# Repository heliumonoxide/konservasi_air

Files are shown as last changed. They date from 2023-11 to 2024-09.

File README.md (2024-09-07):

# Water Quality Monitoring Device
Banner Github Water Quality Monitoring
## Introduction
This project is **a Water Quality Monitoring System** supported by both a web interface and an OLED display. The device utilizes the SPIFFS (SPI Flash File System) feature of the ESP32 microcontroller to deploy a native web application (HTML, CSS, JavaScript) over a wide-area local network. The system directly links the web interface to real-time data received by the ESP32, providing users with seamless access to water quality metrics. 
 
### Concerns
The Drinking Fountain is essential for students at the Faculty of Engineering, Universitas Indonesia, providing water and reducing plastic use. However, concerns about water quality have led 60% of students to still purchase bottled water. A survey revealed that 90% of respondents believe the water quality in certain buildings is poor, particularly due to its taste. Addressing these concerns is crucial to encouraging students to trust and use the water fountains.

### Usage
1. The device measures all test parameters on drinking water samples.
2. It displays results in a human-readable format via an OLED screen.
3. The device sends water test data to a designed webpage.
4. Its microcontroller deploys a server-based webpage accessible to anyone on the UI Wi-Fi, providing water fountain quality information.

## PCB Design
PCB made using Altium and printed using PCB printing machine.
\


> Here are the made PCB picture
> \
> 
## Hardware Design
HardwareDesign-ezgif com-video-to-gif-converter

## Requirements Software
For installation, within Arduino IDE, the following libraries needs to be installed under Sketch -> Include Library -> Manage Libraries:
* ArduinoJson by Benoit Blanchon
* WebSockets by Markus Sattler
* WiFi 

The following to libraries need to be downloaded, unpacked and copied to the "Arduino" folder (Required for ESPAsyncWebServer)
- https://github.com/me-no-dev/ESPAsyncWebServerWater
- https://github.com/me-no-dev/AsyncTCP

Required to make SPIFFS.h work:
https://github.com/me-no-dev/arduino-esp32fs-plugin/releases/

### How to Install Packages Manually
- Click on the link provided in each package
- Download zip file of the packages through the 'code' dropdown
- Unzip/extract the downloaded file
- Put the packages folder in to libraries folder in Arduino Folder (usually in C:/Users/Documents/Arduino)

### How to Install Tools Manually
- Click on the link provided in each package
- Download zip file of the tools in the asset section of the page
- Unzip/extract the downloaded file
- Put the asset folder into tools folder in Arduino Folder (usually in C:/Users/Documents/Arduino)
- After putting asset folder into tools folder, restart the Arduino IDE
- Check if in the dropdown section of Tools there is ESP32 Sketch Data Upload
- [X] if there is, then you are set to go

## Code Pre-configuration
In the ino. files in this section,
```
// SSID and password of Wifi connection:
const char* ssid = "[Your Wifi Name]";
const char* password = "[Your Wifi Password]";
```
ssid and password need to be changed according to the router/wifi that is used.

> Before uploading the code, **please upload data sketch first using ESP32 Sketch Data Upload button on tools dropdown section**

## Hardware Requirement
Before making the actual device, there are some items that you need to have:
- Analog pH Sensor kit by DFRobot
- OleD White 0.96 inch I2C IIC 128x64 display module lcd
- Oled Display 0.91 inch 128x32 LCD Screen
- Micro DC step down 4v-24v to 3.3v 5v 3A Buck super mini
- ESP32
- KY-023 Analog Dual Axis XY Joystick
- Calibration Buffer Powder/liquid
- PH Meter Sensor board ph4502C for Arduino
- Robotdyn e 3.3v/5v logic 4A/16A 600V for Arduino - 4A
- PTC Thermostat
- Heatsink
- Hi-Link HLK-5M05
- Modul 16bit I2C ADS1115
- Jumper set
- NTC Thermistor
- TDS Sensor
- Turbidity Sensor
- Servo

> Before using all the sensor, please configurate and calibrate first.
## Created by
Bryan Indarto, Aldy Raja, Theonaldo, dan Reza Febrian

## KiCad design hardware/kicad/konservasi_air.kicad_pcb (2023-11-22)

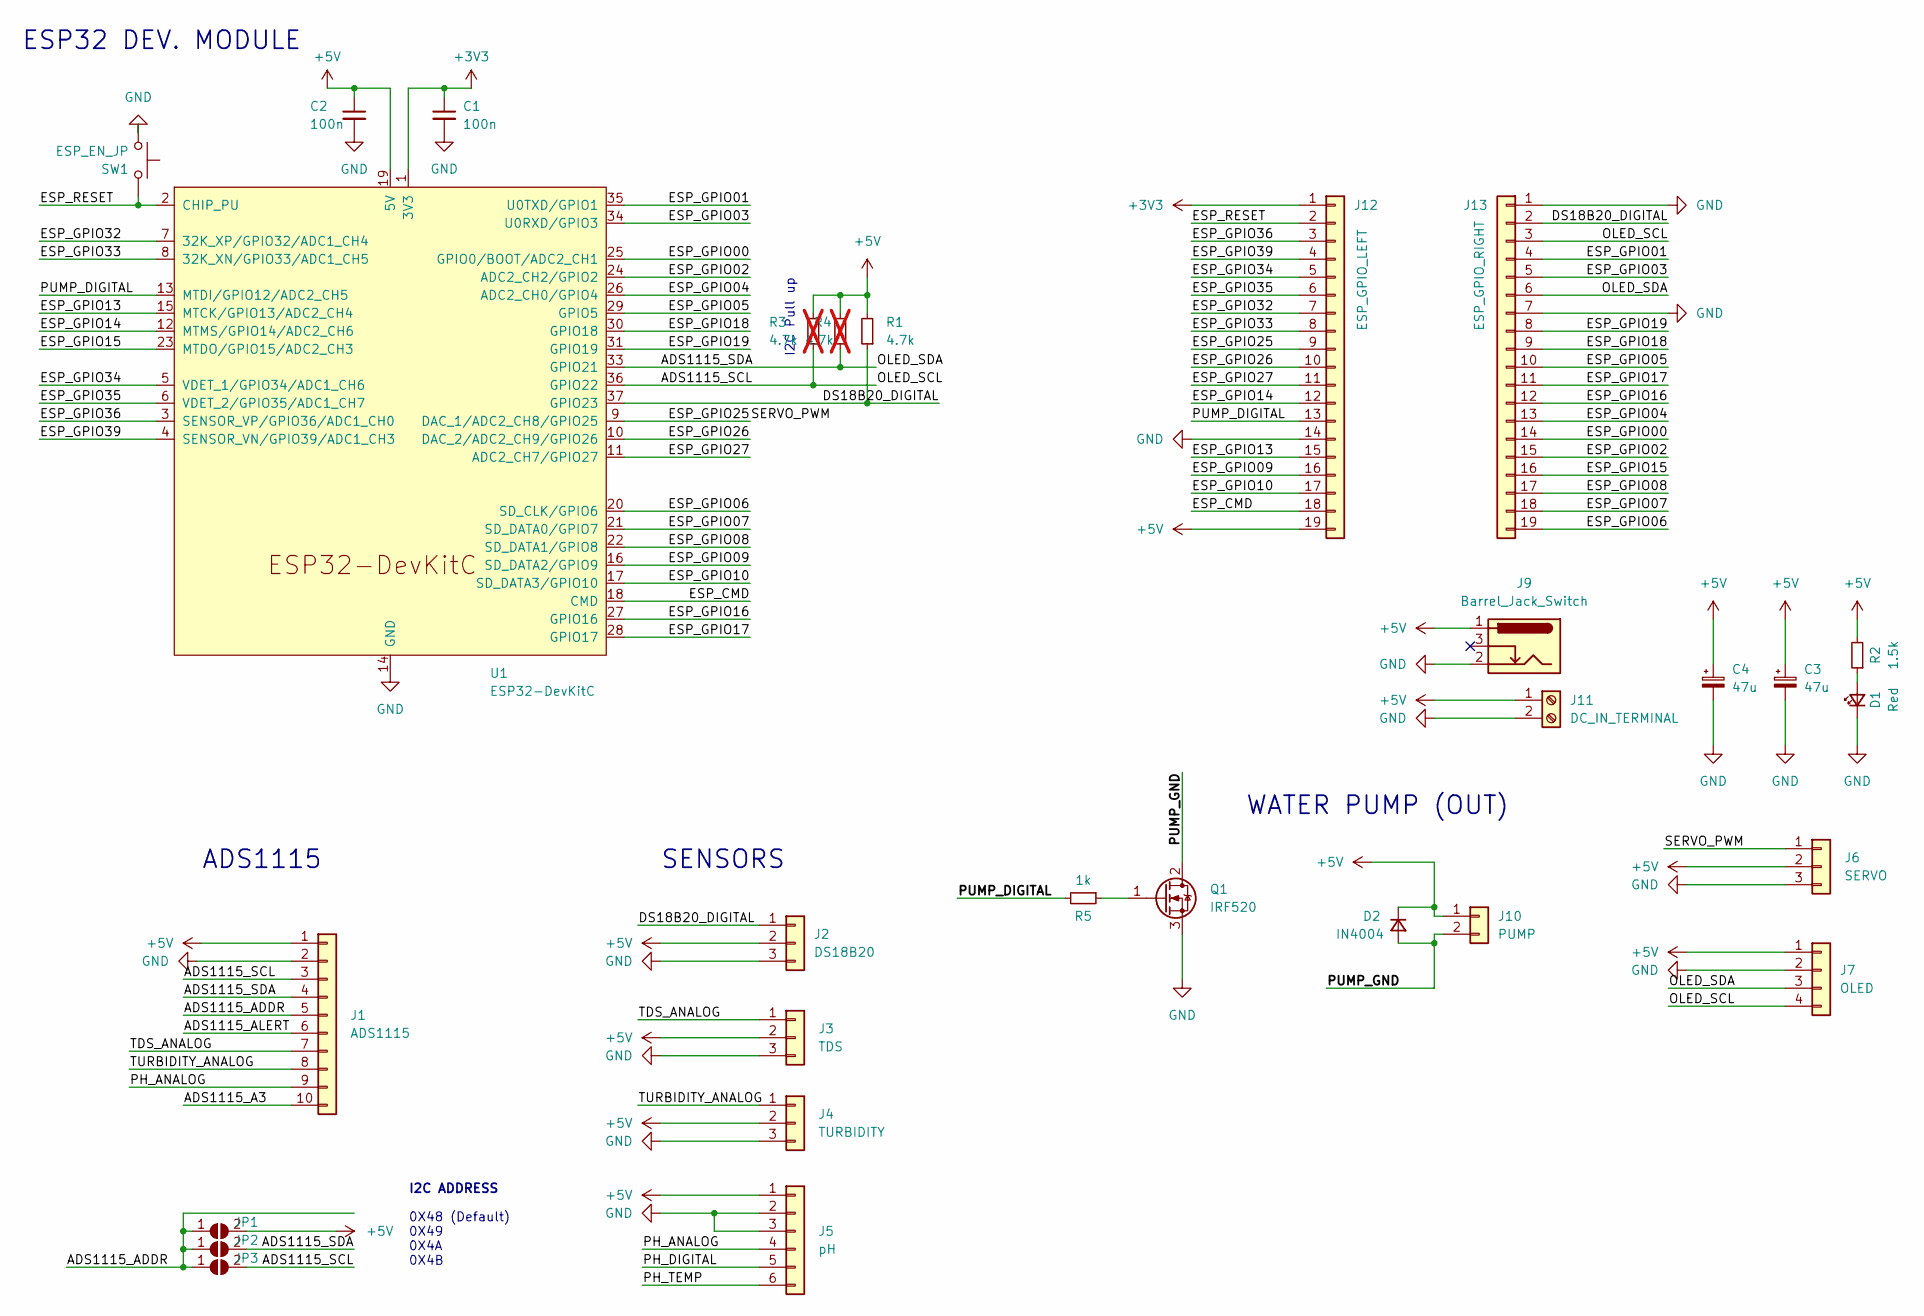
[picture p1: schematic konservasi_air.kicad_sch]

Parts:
C1, C2: 100n; C_Disc_D5.0mm_W2.5mm_P5.00mm
C3, C4: 47u; C_Radial_D5.0mm_H11.0mm_P2.00mm
D1: Red; LED_D3.0mm
D2: IN4004; D_DO-34_SOD68_P7.62mm_Horizontal
J1: ADS1115; PinSocket_1x10_P2.54mm_Vertical
J2: DS18B20; Molex_SL_171971-0003_1x03_P2.54mm_Vertical
J3: TDS; Molex_SL_171971-0003_1x03_P2.54mm_Vertical
J4: TURBIDITY; Molex_SL_171971-0003_1x03_P2.54mm_Vertical
J5: pH; Molex_SL_171971-0006_1x06_P2.54mm_Vertical
J6: SERVO; Molex_SL_171971-0003_1x03_P2.54mm_Vertical
J7: OLED; Molex_SL_171971-0004_1x04_P2.54mm_Vertical
J9: Barrel_Jack_Switch; BarrelJack_Horizontal
J10: PUMP; Molex_SL_171971-0002_1x02_P2.54mm_Vertical
J11: DC_IN_TERMINAL; TerminalBlock_Phoenix_MPT-0,5-2-2.54_1x02_P2.54mm_Horizontal
J12: ESP_GPIO_LEFT; PinHeader_1x19_P2.54mm_Vertical
J13: ESP_GPIO_RIGHT; PinHeader_1x19_P2.54mm_Vertical
JP1: ADS1115_ADDR_5V; SolderJumper-2_P1.3mm_Open_RoundedPad1.0x1.5mm
JP2: ADS1115_ADDR_SDA; SolderJumper-2_P1.3mm_Open_RoundedPad1.0x1.5mm
JP3: ADS1115_ADDR_SCL; SolderJumper-2_P1.3mm_Open_RoundedPad1.0x1.5mm
Q1: IRF520; TO-220-3_Vertical
R1: 4.7k; R_Axial_DIN0204_L3.6mm_D1.6mm_P7.62mm_Horizontal
R2: 1.5k; R_Axial_DIN0204_L3.6mm_D1.6mm_P7.62mm_Horizontal
R3, R4: 4.7k; R_Axial_DIN0204_L3.6mm_D1.6mm_P7.62mm_Horizontal; not fitted
R5: 1k; R_Axial_DIN0204_L3.6mm_D1.6mm_P7.62mm_Horizontal
SW1: ESP_EN_JP; Molex_SL_171971-0002_1x02_P2.54mm_Vertical
U1: ESP32-DevKitC

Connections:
+3V3: C1.1, J12.1, U1.1 (3V3)
+5V: C2.1, C3.1, C4.1, D2.1 (K), J1.1, J2.2, J3.2, J4.2, J5.1, J6.2, J7.1, J9.1, J10.1, J11.1, J12.19, JP1.2 (B), R1.2, R2.2, R3.2, R4.2, U1.19 (5V)
/ADS1115_A3: J1.10
/ADS1115_ADDR: J1.5, JP1.1 (A), JP2.1 (A), JP3.1 (A)
/ADS1115_ALERT: J1.6
/ADS1115_SCL: J1.3, J7.4, J13.3, JP3.2 (B), R3.1, U1.36 (GPIO22)
/ADS1115_SDA: J1.4, J7.3, J13.6, JP2.2 (B), R4.1, U1.33 (GPIO21)
/DS18B20_DIGITAL: J2.1, J13.2, R1.1, U1.37 (GPIO23)
/ESP_CMD: J12.18, U1.18 (CMD)
/ESP_GPIO00: J13.14, U1.25 (GPIO0/BOOT/ADC2_CH1)
/ESP_GPIO01: J13.4, U1.35 (U0TXD/GPIO1)
/ESP_GPIO02: J13.15, U1.24 (ADC2_CH2/GPIO2)
/ESP_GPIO03: J13.5, U1.34 (U0RXD/GPIO3)
/ESP_GPIO04: J13.13, U1.26 (ADC2_CH0/GPIO4)
/ESP_GPIO05: J13.10, U1.29 (GPIO5)
/ESP_GPIO06: J13.19, U1.20 (SD_CLK/GPIO6)
/ESP_GPIO07: J13.18, U1.21 (SD_DATA0/GPIO7)
/ESP_GPIO08: J13.17, U1.22 (SD_DATA1/GPIO8)
/ESP_GPIO09: J12.16, U1.16 (SD_DATA2/GPIO9)
/ESP_GPIO10: J12.17, U1.17 (SD_DATA3/GPIO10)
/ESP_GPIO13: J12.15, U1.15 (MTCK/GPIO13/ADC2_CH4)
/ESP_GPIO14: J12.12, U1.12 (MTMS/GPIO14/ADC2_CH6)
/ESP_GPIO15: J13.16, U1.23 (MTDO/GPIO15/ADC2_CH3)
/ESP_GPIO16: J13.12, U1.27 (GPIO16)
/ESP_GPIO17: J13.11, U1.28 (GPIO17)
/ESP_GPIO18: J13.9, U1.30 (GPIO18)
/ESP_GPIO19: J13.8, U1.31 (GPIO19)
/ESP_GPIO25: J6.1, J12.9, U1.9 (DAC_1/ADC2_CH8/GPIO25)
/ESP_GPIO26: J12.10, U1.10 (DAC_2/ADC2_CH9/GPIO26)
/ESP_GPIO27: J12.11, U1.11 (ADC2_CH7/GPIO27)
/ESP_GPIO32: J12.7, U1.7 (32K_XP/GPIO32/ADC1_CH4)
/ESP_GPIO33: J12.8, U1.8 (32K_XN/GPIO33/ADC1_CH5)
/ESP_GPIO34: J12.5, U1.5 (VDET_1/GPIO34/ADC1_CH6)
/ESP_GPIO35: J12.6, U1.6 (VDET_2/GPIO35/ADC1_CH7)
/ESP_GPIO36: J12.3, U1.3 (SENSOR_VP/GPIO36/ADC1_CH0)
/ESP_GPIO39: J12.4, U1.4 (SENSOR_VN/GPIO39/ADC1_CH3)
/ESP_RESET: J12.2, SW1.2, U1.2 (CHIP_PU)
/PH_ANALOG: J1.9, J5.4
/PH_DIGITAL: J5.5
/PH_TEMP: J5.6
/PUMP_DIGITAL: J12.13, R5.2, U1.13 (MTDI/GPIO12/ADC2_CH5)
/PUMP_GND: D2.2 (A), J10.2, Q1.2 (D)
/TDS_ANALOG: J1.7, J3.1
/TURBIDITY_ANALOG: J1.8, J4.1
GND: C1.2, C2.2, C3.2, C4.2, D1.1 (K), J1.2, J2.3, J3.3, J4.3, J5.2, J5.3, J6.3, J7.2, J9.2, J11.2, J12.14, J13.1, J13.7, Q1.3 (S), SW1.1, U1.14 (GND), U1.32 (GND), U1.38 (GND)
unnamed: D1.2 (A), R2.1
unnamed: Q1.1 (G), R5.1

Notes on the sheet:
ESP32 DEV. MODULE
ADS1115
I2C Pull up
WATER PUMP (OUT)
I2C ADDRESS
0X48 (Default) 0X49 0X4A 0X4B
SENSORS

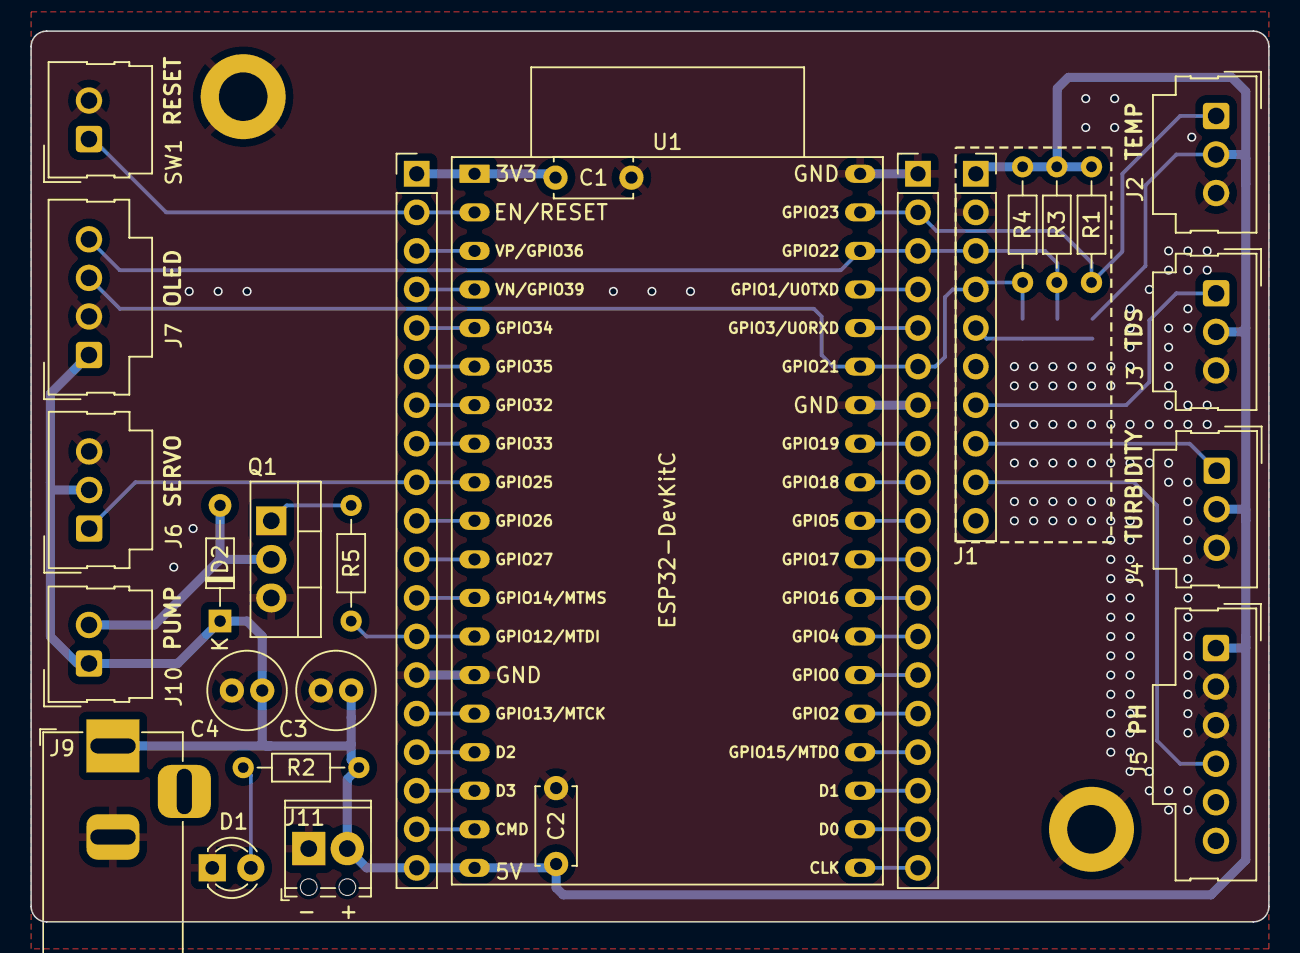
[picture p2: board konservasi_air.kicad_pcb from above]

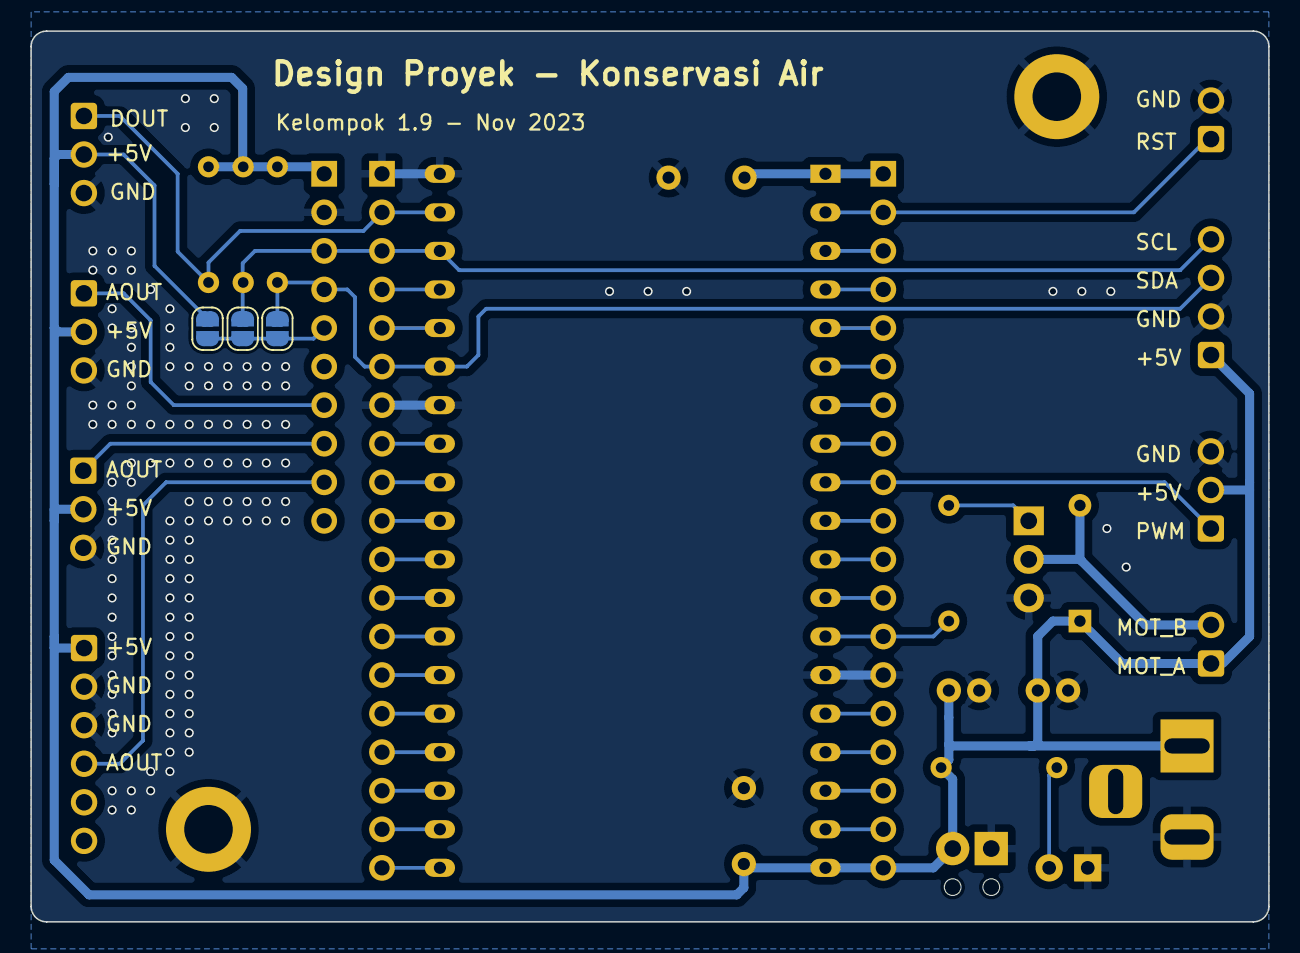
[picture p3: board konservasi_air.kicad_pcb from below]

Board: 2 copper layers, 81.5 x 58.7 mm, 29 parts (3 on the bottom side), 43 nets.

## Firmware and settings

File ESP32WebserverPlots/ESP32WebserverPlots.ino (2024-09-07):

// ---------------------------------------------------------------------------------------
// For installation, the following library needs to be installed under Sketch -> Include Library -> Manage Libraries:
// * ArduinoJson by Benoit Blanchon
//
// The following to libraries need to be downloaded, unpacked and copied to the "Arduino\libraries" folder
// (Required for ESPAsyncWebServer)
// https://github.com/me-no-dev/ESPAsyncWebServer
// https://github.com/me-no-dev/AsyncTCP
//
// Required to make SPIFFS.h work:
// https://github.com/me-no-dev/arduino-esp32fs-plugin/releases/
// see as well: https://randomnerdtutorials.com/install-esp32-filesystem-uploader-arduino-ide/
// ---------------------------------------------------------------------------------------

/***************************************************
 Created by Kelompok Despro:
 - Bryan Indarto Giovanni Firjatulloh
 - Aldy Raja Sipahutar 
 ****************************************************/

// Library for Webserver
#include <WiFi.h>                                     // needed to connect to WiFi
#include <ESPAsyncWebServer.h>                        // needed to create a simple webserver (make sure tools -> board is set to ESP32, otherwise you will get a "WebServer.h: No such file or directory" error)
#include <WebSocketsServer.h>                         // needed for instant communication between client and server through Websockets
#include <ArduinoJson.h>                              // needed for JSON encapsulation (send multiple variables with one string)
#include <SPIFFS.h>
#include <AsyncElegantOTA.h>
// Hardware Initialization
#include <OneWire.h>
#include <DallasTemperature.h>
#include <ESP32Servo.h>
#include "DFRobot_PH.h"
#include <EEPROM.h>
#include <SPI.h>
#include <Wire.h>
#include <Adafruit_GFX.h>
#include <Adafruit_SSD1306.h>
#include <Adafruit_ADS1X15.h>

#define TEMP_PIN 23 // Yellow cable on temp-liquid sensor pin

#define PIN_SERVO1 25
#define PUMP_PIN 12
#define SCREEN_WIDTH 128 // OLED display width, in pixels
#define SCREEN_HEIGHT 64 // OLED display height, in pixels
#define OLED_RESET     -1 // Reset pin # (or -1 if sharing Arduino reset pin)

// Declaration for an SSD1306 display connected to I2C (SDA, SCL pins)
Adafruit_SSD1306 display(SCREEN_WIDTH, SCREEN_HEIGHT, &Wire, OLED_RESET);

Adafruit_ADS1115 ads;

int16_t adc0, adc1, adc2;
float volts0, volts1, volts2;

// SSID and password of Wifi connection:
const char* ssid = "HotSpot - UI";
const char* password = "";

const int ARRAY_LENGTH = 5;  // final_quality, temperature_value, ph_value, ntu_value, tds_value (Currently only for 5 sensors on 1 Niagara place)
int sensors_val[ARRAY_LENGTH];

// We want to periodically send values to the clients, so we need to define an "interval" and remember the last time we sent data to the client (with "previousMillis")
int interval = 60000;                                  // send data to the client every 2000ms -> 2s
unsigned long previousMillis = 0;                     // we use the "millis()" command for time reference and this will output an unsigned long

// Initialization of webserver and websocket
AsyncWebServer server(80);                            // the server uses port 80 (standard port for websites
WebSocketsServer webSocket = WebSocketsServer(81);    // the websocket uses port 81 (standard port for websockets

// Initialization of the hardware
unsigned long startTime;

// Temperature Sensor Parameter
float tempValue;
OneWire oneWire(TEMP_PIN); // Setup a oneWire instance to communicate with any OneWire devices
DallasTemperature sensors(&oneWire); // Pass our oneWire reference to Dallas Temperature sensor 

// TDS Sensor Parameter
#define SCOUNT  30           // sum of sample point
int analogBuffer[SCOUNT];    // store the analog value in the array, read from ADC
int analogBufferTemp[SCOUNT];
int analogBufferIndex = 0,copyIndex = 0;
float averageVoltage = 0,tdsValue = 0,temperature = 25;
unsigned long startTimeBuffer = 0;
unsigned long currentTimeBuffer;
unsigned long startTimeTDS = 0;

float result;

// NTU
float ntu = 0;

// pH Sensor Parameter
#define Offset 0.00    
#define ArrayLength  40    //times of collection
static unsigned long start_pHSamplingTime = 0;
static unsigned long start_pHPrintTime = 0;
int pHArray[ArrayLength];   //Store the average value of the sensor feedback
int pHArrayIndex=0;
float pHValue,pHvoltage;
DFRobot_PH ph;

// Flags
bool exec_measurement = false;
int counter = 0;

// Servo
Servo servo1;
const int sudut_trigger_open = 135;
const int sudut_close = 0;
const int sudut_trigger_close = 0;
const int sudut_open = 135;
int pos = 0;    // variable to store the servo position

void webSocketEvent(byte num, WStype_t type, uint8_t * payload, size_t length);

void setup() {
  Serial.begin(115200);                               // init serial port for debugging
  ads.begin();

  if (!SPIFFS.begin()) {
    Serial.println("SPIFFS could not initialize");
  }
  
// ================================================== ganti wifi ==================================================
  WiFi.begin(ssid, password);                         // start WiFi interface
  Serial.println("Establishing connection to WiFi with SSID: " + String(ssid));     // print SSID to the serial interface for debugging
 
  while (WiFi.status() != WL_CONNECTED) {             // wait until WiFi is connected
    delay(1000);
    Serial.print(".");
  }
  Serial.print("Connected to network with IP address: ");
  Serial.println(WiFi.localIP());                     // show IP address that the ESP32 has received from router
// ================================================================================================================
  
  server.on("/", HTTP_GET, [](AsyncWebServerRequest *request) {    // define here what the webserver needs to do
    request->send(SPIFFS, "/webpage.html", "text/html");           
  });

  server.onNotFound([](AsyncWebServerRequest *request) {
    request->send(404, "text/plain", "File not found");
  });

  server.serveStatic("/", SPIFFS, "/");
  
  webSocket.begin();                                  // start websocket
  webSocket.onEvent(webSocketEvent);                  // define a callback function -> what does the ESP32 need to do when an event from the websocket is received? -> run function "webSocketEvent()"

  AsyncElegantOTA.begin(&server);    // Start AsyncElegantOTA
  
  server.begin();                                     // start server -> best practise is to start the server after the websocket

  // SSD1306_SWITCHCAPVCC = generate display voltage from 3.3V internally
  if(!display.begin(SSD1306_SWITCHCAPVCC, 0x3C)) { 
    Serial.println(F("SSD1306 allocation failed"));
    for(;;); // Don't proceed, loop forever
  }
  display.clearDisplay();
  display.drawRect(6, 6, display.width()-6*2, display.height()-6*2, WHITE);
  display.fillRect(6, 6, display.width()-6*2, 14, WHITE);
  display.setTextSize(1);             // Normal 1:1 pixel scale
  display.setCursor(10, 10);
  display.setTextColor(BLACK, WHITE); // Draw 'inverse' text
  display.print(F("NIAGARA MONITORING"));
  display.setCursor(10, 24);
  display.setTextColor(WHITE);        // Draw white text
  display.print(F("IP: ")); display.print(WiFi.localIP());
  display.display();

  // Device Wiring Part
  pinMode(PUMP_PIN, OUTPUT);
  digitalWrite(PUMP_PIN, LOW);
  
  servo1.attach(PIN_SERVO1);

  sensors.begin();
  startTime = millis();
  startTimeBuffer = millis();
  startTimeTDS = millis();
  start_pHSamplingTime = millis();
  start_pHPrintTime = millis();
  servo1.write(0);
  delay(1000);
}

// sendJsonArray used for final_quality, temperature_value, ph_value, ntu_value, tds_value
void loop()
{
  add_buffer(); // Data Additional Sensor TDS
  if(counter == 0 || (millis() - startTime >= 30000) || exec_measurement == true){
    if (exec_measurement == false){
  for (pos = sudut_trigger_close; pos <= sudut_trigger_open; pos += 1) { // goes from 0 degrees to 180 degrees
    // in steps of 1 degree
    servo1.write(pos);    // tell servo to go to position in variable 'pos'
    delay(10);             // waits 15ms for the servo to reach the position
  }
  delay(10000);
  for (pos = sudut_trigger_open; pos >= sudut_trigger_close; pos -= 1) { // goes from 180 degrees to 0 degrees
    servo1.write(pos);    // tell servo to go to position in variable 'pos'
    delay(10);             // waits 15ms for the servo to reach the position
  }
      exec_measurement = true;
    }

    delay(10);
    
    if(exec_measurement == true){
      Serial.println("start measurement");
      
      // Sensor Suhu
      sensors.requestTemperatures();
      tempValue = sensors.getTempCByIndex(0);
      Serial.println("=====================================");
      Serial.print("Temp Celsius: ");
      Serial.print(tempValue);
      Serial.println(" C \n");
  
      // Sensor Turbidity
      int sensorValue = ads.readADC_SingleEnded(1);// read the input on analog pin ads A1:
      Serial.print("Analog Value: ");
      Serial.println(sensorValue);
      float voltage = ads.computeVolts(sensorValue); // Convert the analog reading (which goes from 0 - 4096) to a voltage (0 - 3.3V):
      ntu = (-1120.4*(voltage*voltage)) + (5742.3*voltage) - 4352.9;



      ntu = -ntu;    // Hard-Coded
      ntu = map(ntu, 0, 5000, 2.5, 0);


      
      Serial.print("Turbidity Voltage: ");
      Serial.println(voltage); // print out the value you read:
      Serial.print("Turbidity NTU: ");
      Serial.println(ntu);
      Serial.print("\n");
      
      // Sensor TDS
      print_tds();
  
      // Sensor pH
      pH_buffer();

      Serial.println("=====================================");
      
      if(counter == 4){
        exec_measurement = false;
        startTime = millis();
        digitalWrite(PUMP_PIN, HIGH);
        delay(10000);
        digitalWrite(PUMP_PIN, LOW);
        delay(500);
        counter = 0;
      }
      counter += 1;
    }
  }
  webSocket.loop();                                   // Update function for the webSockets 
  unsigned long now = millis();                       // read out the current "time" ("millis()" gives the time in ms since the Arduino started)
  if ((unsigned long)(now - previousMillis) > interval) { // check if "interval" ms has passed since last time the clients were updated
    previousMillis = now;                             // reset previousMillis
    
    sensors_val[0] = result;
    sensors_val[1] = tempValue;
    sensors_val[2] = pHValue;
    sensors_val[3] = ntu;
    sensors_val[4] = tdsValue;



    result = 3.0;
    if(sensors_val[2] > 6 && sensors_val[2] < 11) result = 8.0;

    

    sendJsonArray("dashboard_update", sensors_val);

  }
  drawSensVal();    // Draw sensor value
}

void webSocketEvent(byte num, WStype_t type, uint8_t * payload, size_t length) {      // the parameters of this callback function are always the same -> num: id of the client who send the event, type: type of message, payload: actual data sent and length: length of payload
  switch (type) {                                     // switch on the type of information sent
    case WStype_DISCONNECTED:                         // if a client is disconnected, then type == WStype_DISCONNECTED
      Serial.println("Client " + String(num) + " disconnected");
      break;
    case WStype_CONNECTED:                            // if a client is connected, then type == WStype_CONNECTED
      Serial.println("Client " + String(num) + " connected");
      
      // send variables to newly connected web client -> as optimization step one could send it just to the new client "num", but for simplicity I left that out here
      // sendJson("random_intensity", String(random_intensity));
      sendJsonArray("dashboard_update", sensors_val);

      break;
    case WStype_TEXT:                                 // if a client has sent data, then type == WStype_TEXT
      // try to decipher the JSON string received
      StaticJsonDocument<200> doc;                    // create JSON container 
      DeserializationError error = deserializeJson(doc, payload);
      if (error) {
         Serial.print(F("deserializeJson() failed: "));
        Serial.println(error.f_str());
        return;
      }
      else {
        // JSON string was received correctly, so information can be retrieved:
        const char* l_type = doc["type"];
        const int l_value = doc["value"];
        Serial.println("Type: " + String(l_type));
        Serial.println("Value: " + String(l_value));
      }
      Serial.println("");
      break;
  }
}

// Simple function to send information to the web clients
void sendJsonArray(String l_type, int l_array_values[]) {
    String jsonString = "";                           // create a JSON string for sending data to the client
    const size_t CAPACITY = JSON_ARRAY_SIZE(ARRAY_LENGTH) + 100;
    StaticJsonDocument<CAPACITY> doc;                      // create JSON container
    
    JsonObject object = doc.to<JsonObject>();         // create a JSON Object
    object["type"] = l_type;                          // write data into the JSON object
    JsonArray value = object.createNestedArray("value");
    for(int i=0; i<ARRAY_LENGTH; i++) {
      value.add(l_array_values[i]);
    }
    serializeJson(doc, jsonString);                   // convert JSON object to string
    webSocket.broadcastTXT(jsonString);               // send JSON string to all clients
}


void add_buffer(void){
//  Serial.println("Adding Buffer for TDS");
  currentTimeBuffer = millis();
  if(currentTimeBuffer - startTimeBuffer > 40UL)     //every 40 milliseconds,read the analog value from the ADC
  {
   analogBuffer[analogBufferIndex] = ads.readADC_SingleEnded(0);    //read the analog value and store into the buffer
   analogBufferIndex++;
   if(analogBufferIndex == SCOUNT){
    analogBufferIndex = 0; 
   }
   startTimeBuffer = currentTimeBuffer;
  }
}

void print_tds(void){
  unsigned long currentTimeTDS = millis();
  for(copyIndex=0;copyIndex<SCOUNT;copyIndex++){
    analogBufferTemp[copyIndex]= analogBuffer[copyIndex];
  }
  
  averageVoltage = ads.computeVolts(getMedianNum(analogBufferTemp,SCOUNT)); // read the analog value more stable by the median filtering algorithm, and convert to voltage value
  float compensationCoefficient=1.0+0.02*(temperature-25.0);    //temperature compensation formula: fFinalResult(25^C) = fFinalResult(current)/(1.0+0.02*(fTP-25.0));
  float compensationVolt=averageVoltage/compensationCoefficient;  //temperature compensation
  tdsValue=(133.42*compensationVolt*compensationVolt*compensationVolt - 255.86*compensationVolt*compensationVolt + 857.39*compensationVolt)*0.5; //convert voltage value to tds value



  if(tdsValue < 175 || tdsValue > 350) {
    tdsValue = random(175, 215);
  }


  
  //Serial.print("voltage:");
  //Serial.print(averageVoltage,2);
  //Serial.print("V   ");
  Serial.print("TDS Value:");
  Serial.print(tdsValue);
  Serial.println("ppm");
  startTimeTDS = currentTimeTDS;
}


void pH_buffer(void) {
 while(true)
  {
    pHArray[pHArrayIndex++]=ads.readADC_SingleEnded(2);  // pH
    pHvoltage = ads.computeVolts(averagearray(pHArray, ArrayLength));
    pHValue = 3.5*pHvoltage+Offset;


    
    pHValue -= 1.8;    // Hard-Coded
    if(pHValue > 9 && pHValue < 11.5){
      pHValue = random(7, 8);
    }
    

    
    if(pHArrayIndex==ArrayLength){
      pHArrayIndex=0;
      break;
    }
  }
}

int getMedianNum(int bArray[], int iFilterLen) 
{
      int bTab[iFilterLen];
      for (byte i = 0; i<iFilterLen; i++)
      bTab[i] = bArray[i];
      int i, j, bTemp;
      for (j = 0; j < iFilterLen - 1; j++) 
      {
      for (i = 0; i < iFilterLen - j - 1; i++) 
          {
        if (bTab[i] > bTab[i + 1]) 
            {
        bTemp = bTab[i];
            bTab[i] = bTab[i + 1];
        bTab[i + 1] = bTemp;
         }
      }
      }
      if ((iFilterLen & 1) > 0)
    bTemp = bTab[(iFilterLen - 1) / 2];
      else
    bTemp = (bTab[iFilterLen / 2] + bTab[iFilterLen / 2 - 1]) / 2;
      return bTemp;
}

double averagearray(int* arr, int number){
  int i;
  int max,min;
  double avg;
  long amount=0;
  if(number<=0){
    Serial.println("Error number for the array to avraging!/n");
    return 0;
  }
  if(number<5){   //less than 5, calculated directly statistics
    for(i=0;i<number;i++){
      amount+=arr[i];
    }
    avg = amount/number;
    return avg;
  }else{
    if(arr[0]<arr[1]){
      min = arr[0];max=arr[1];
    }
    else{
      min=arr[1];max=arr[0];
    }
    for(i=2;i<number;i++){
      if(arr[i]<min){
        amount+=min;        //arr<min
        min=arr[i];
      }else {
        if(arr[i]>max){
          amount+=max;    //arr>max
          max=arr[i];
        }else{
          amount+=arr[i]; //min<=arr<=max
        }
      }//if
    }//for
    avg = (double)amount/(number-2);
  }//if
  return avg;
}

void drawSensVal(void) {
  display.clearDisplay();
  display.drawRect(6, 6, display.width()-6*2, display.height()-6*2, WHITE);
  display.fillRect(6, 6, display.width()-6*2, 14, WHITE);

  display.setTextSize(1);             // Normal 1:1 pixel scale
  display.setCursor(10, 10);
  display.setTextColor(BLACK, WHITE); // Draw 'inverse' text
  display.print(F("NIAGARA MONITORING"));

  display.setCursor(10, 24);
  display.setTextColor(WHITE);        // Draw white text
  display.print(F("IP: ")); display.print(WiFi.localIP());

  display.setTextSize(2);             // Draw 2X-scale text
  display.setCursor(10, 37);
  display.print(F("Stat:"));
  (sensors_val[2] > 6 && sensors_val[2] < 11)? display.println("GOOD") : display.println("BAD");

  display.display();
  delay(2000);


  display.clearDisplay();
  display.drawRect(6, 6, display.width()-6*2, display.height()-6*2, WHITE);
  display.setTextSize(1);
  display.setCursor(10, 10);
  display.println(F("pH: "));
  display.setTextSize(2);
  display.print("  "); display.println(sensors_val[2]);

  display.setTextSize(1);
  display.setCursor(10, 33);
  display.println(F("Turb: "));
  display.setTextSize(2);
  display.print("  "); display.println(sensors_val[3]);
  display.display();
  delay(2000);

  display.clearDisplay();
  display.drawRect(6, 6, display.width()-6*2, display.height()-6*2, WHITE);
  display.setTextSize(1);
  display.setCursor(10, 10);
  display.println(F("Temp: "));

  display.setTextSize(2);
  display.print("  "); display.println(sensors_val[1]);

  display.setTextSize(1);
  display.setCursor(10, 33);
  display.println(F("TDS: "));
  display.setTextSize(2);
  display.print("  "); display.println(sensors_val[4]);
  display.display();
  delay(2000);
}

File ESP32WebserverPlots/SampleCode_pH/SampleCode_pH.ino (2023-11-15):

///*
// # This sample code is used to test the pH meter V1.0.
// # Editor : YouYou
// # Ver    : 1.0
// # Product: analog pH meter
// # SKU    : SEN0161
//*/
//#define SensorPin A0            //pH meter Analog output to Arduino Analog Input 0
//#define Offset 0            //deviation compensate
//#define LED 13
//#define samplingInterval 20
//#define printInterval 800
//#define ArrayLenth  40    //times of collection
//int pHArray[ArrayLenth];   //Store the average value of the sensor feedback
//int pHArrayIndex=0;
//void setup(void)
//{
//  pinMode(LED,OUTPUT);
//  Serial.begin(115200);
//  Serial.println("pH meter experiment!");    //Test the serial monitor
//  pinMode(SensorPin, INPUT);
//}
//void loop(void)
//{
//  static unsigned long samplingTime = millis();
//  static unsigned long printTime = millis();
//  static float pHValue,voltage;
//  if(millis()-samplingTime > samplingInterval)
//  {
//      pHArray[pHArrayIndex++]=analogRead(SensorPin);
//      if(pHArrayIndex==ArrayLenth)pHArrayIndex=0;
//      voltage = avergearray(pHArray, ArrayLenth)*5.0/1024;
//      pHValue = 3.5*voltage+Offset;
//      samplingTime=millis();
//  }
//  if(millis() - printTime > printInterval)   //Every 800 milliseconds, print a numerical, convert the state of the LED indicator
//  {
//    Serial.print("Voltage:");
//        Serial.print(voltage,2);
//        Serial.print("    pH value: ");
//    Serial.println(pHValue,2);
//        digitalWrite(LED,digitalRead(LED)^1);
//        printTime=millis();
//  }
//}
//double avergearray(int* arr, int number){
//  int i;
//  int max,min;
//  double avg;
//  long amount=0;
//  if(number<=0){
//    Serial.println("Error number for the array to avraging!/n");
//    return 0;
//  }
//  if(number<5){   //less than 5, calculated directly statistics
//    for(i=0;i<number;i++){
//      amount+=arr[i];
//    }
//    avg = amount/number;
//    return avg;
//  }else{
//    if(arr[0]<arr[1]){
//      min = arr[0];max=arr[1];
//    }
//    else{
//      min=arr[1];max=arr[0];
//    }
//    for(i=2;i<number;i++){
//      if(arr[i]<min){
//        amount+=min;        //arr<min
//        min=arr[i];
//      }else {
//        if(arr[i]>max){
//          amount+=max;    //arr>max
//          max=arr[i];
//        }else{
//          amount+=arr[i]; //min<=arr<=max
//        }
//      }//if
//    }//for
//    avg = (double)amount/(number-2);
//  }//if
//  return avg;
//}

#include <Arduino.h>

int pHSense = A0;
int samples = 10;
float adc_resolution = 1024.0;

void setup()
{
    Serial.begin(9600);
    delay(100);
    Serial.println("cimpleo pH Sense");
}

float ph (float voltage) {
    return 7 + ((2.5 - voltage) / 0.18);
}

void loop()
{
    int measurings=0;

    for (int i = 0; i < samples; i++)
    {
        measurings += analogRead(pHSense);
        delay(10);

    }

    float voltage = 5 / adc_resolution * measurings/samples;
    Serial.print("pH= ");
    Serial.println(ph(voltage));
    delay(3000);
}

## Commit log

2023-10-11 Add serial reading for sensor
    reading for sensor 5V
2023-10-11 update Voltage Reference
2023-10-31 pH Sensor Modified
2023-11-02 display sensor values on server
2023-11-10 Up Kicad Project
    [konservasi_air.kicad_pcb, konservasi_air.kicad_sch]
2023-11-10 Update Schematics
    [konservasi_air.kicad_sch]
2023-11-12 PCB Layout Update
    [konservasi_air.kicad_pcb, konservasi_air.kicad_sch]
2023-11-12 PCB Update
    [konservasi_air.kicad_pcb, konservasi_air.kicad_sch]
2023-11-13 Done Routing
    [konservasi_air.kicad_pcb, konservasi_air.kicad_sch]
2023-11-17 PCB Modified
    [konservasi_air.kicad_pcb]
2023-11-17 Update PCB
    [konservasi_air.kicad_pcb]
2023-11-19 Fix Pullup for Temp Sensor
    [konservasi_air.kicad_pcb, konservasi_air.kicad_sch]
2023-11-19 Added Production File (Gerber)
    [konservasi_air.kicad_sch]
2024-09-07 Added functionality to device (#1)
    * final
    * update dikit
    ---------
